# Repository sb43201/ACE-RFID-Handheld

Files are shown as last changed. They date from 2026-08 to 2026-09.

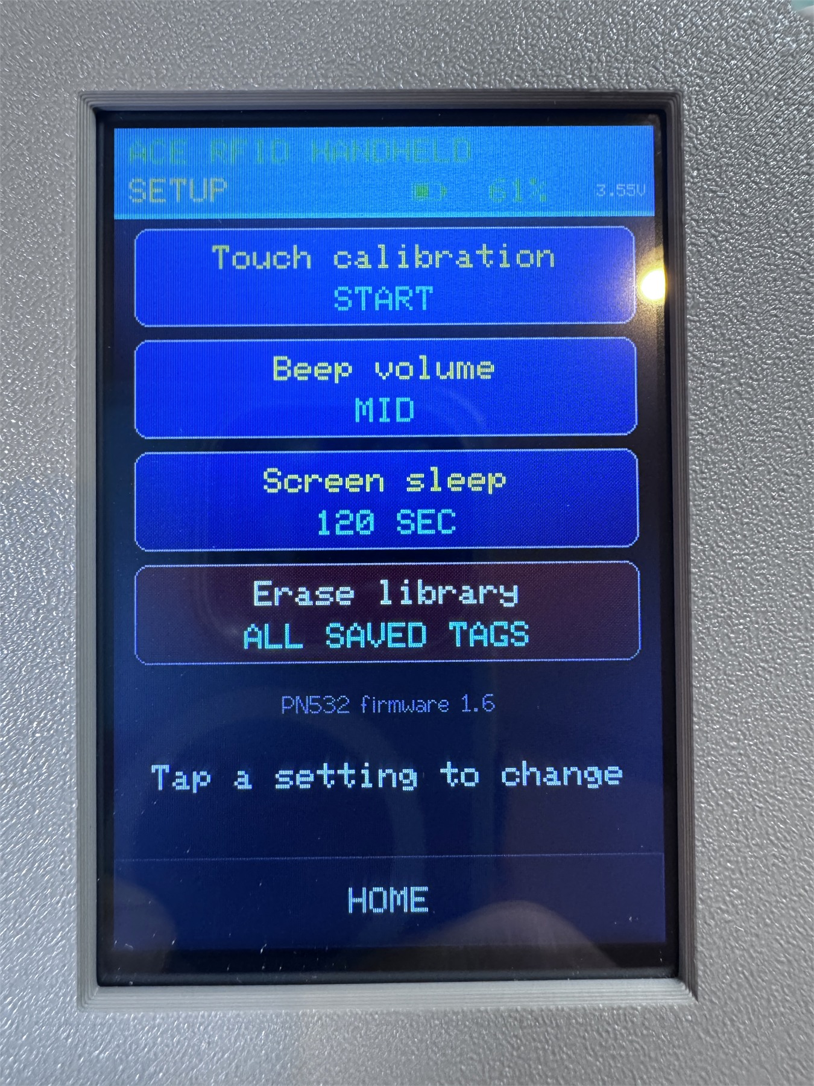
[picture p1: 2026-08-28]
images/09-setup-screen.jpg

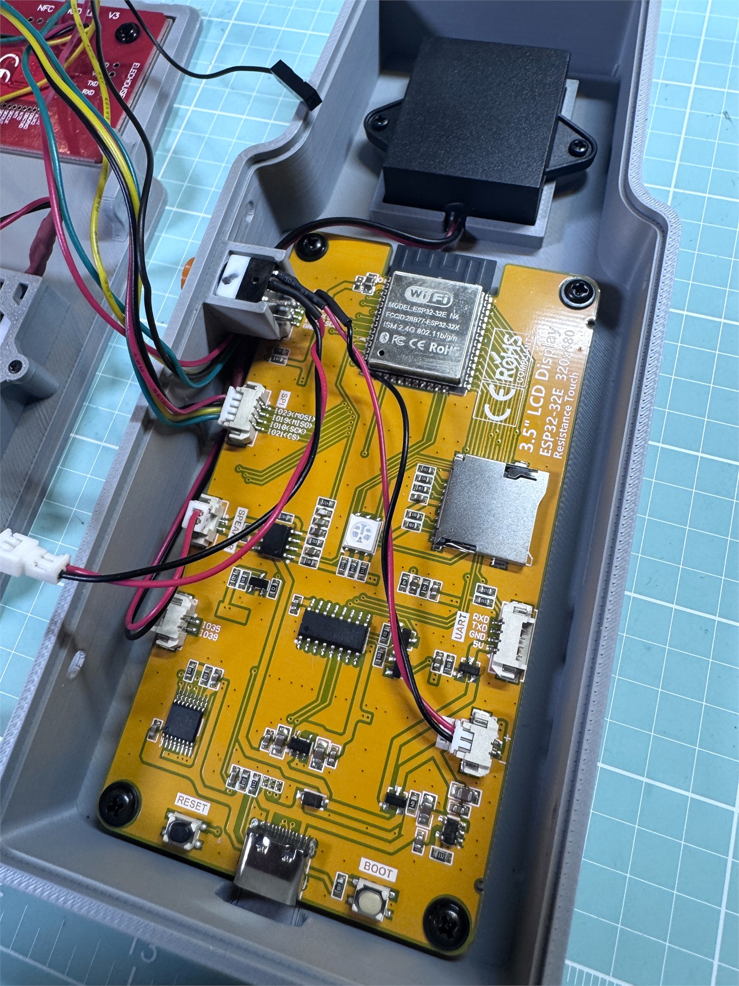
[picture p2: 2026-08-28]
images/02-controller-and-battery.jpg

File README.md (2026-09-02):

# ACE RFID Handheld

Portable ESP32 reader, writer, cloner, read-only emulator, and library for Anycubic ACE filament RFID tags.

The handheld combines a Hosyond/LCDWiki E32R35T 3.5-inch touchscreen with a PN532 NFC module. It reads ACE filament metadata, presents an accessible full-size color plate and color name, writes verified presets to compatible rewritable tags, clones ACE payloads, emulates tags to an ACE reader, and stores scanned or generated presets in onboard flash.

> This is an independent community project. It is not affiliated with or endorsed by Anycubic.

## Highlights

- Reads ACE data from NTAG-compatible tags and decodes material, color, SKU, nozzle range, bed range, diameter, and filament length.
- Large color plate and written color name for color-blind accessibility.
- Writes community, catalog, and factory-captured filament presets.
- Clones the complete ACE payload on pages 4–31 and verifies every byte.
- Emulates scanned, saved, and built-in preset tags in read-only PN532 target mode.
- Shows ACE read progress, blocks write commands during emulation, and provides an on-screen Cancel action.
- Detects factory-locked or incompatible tags and avoids reporting false success.
- Saves scanned tags and generated presets to a CRC-protected LittleFS library with duplicate handling, raw view, rewrite, emulation, and delete.
- Touchscreen setup for calibration, beep volume, and screen timeout.
- Battery icon, percentage, and voltage in the header.
- Wi-Fi and Bluetooth stacks are not linked or initialized, keeping both radios off for an offline, lower-power handheld.
- Musical startup, success, and error cues through the onboard speaker.
- Screen dim/off and touch wake based on the SwitchBot Blind Remote power-management pattern.

## Hardware

- Hosyond/LCDWiki E32R35T with ESP32, ST7796 320×480 TFT, and XPT2046 touch
- Elechouse-style PN532 NFC/RFID V3 module configured for SPI
- Common 3.3 V supply and ground

### Bill of materials

| Qty. | Component | Purchase link | Notes |
|---:|---|---|---|
| 1 | Hosyond 3.5-inch 320×480 Touch Screen ESP32 Display (Cheap Yellow Display) | [Amazon](https://a.co/d/01DXrowN) | Main ESP32, touchscreen, display, battery input, and microSD hardware |
| 1 | PN532 NXP NFC/RFID module | [Amazon](https://a.co/d/03boXSBR) | Configure the module for SPI mode |
| 1 | 3.7 V, 1000 mAh LiPo battery | [Amazon](https://a.co/d/0ji3c6oG) | Verify connector type and polarity before connecting |
| 1 | 4 Ω, 3 W mini speaker | [Amazon](https://a.co/d/07AWv2H9) | Audio feedback and startup/success/error cues |
| 1 | 8×8 mm DPDT tactile switch | [Amazon](https://a.co/d/04x0NMgU) | Power switch |
| 1 kit | 1.25 mm JST/Molex connector kit | [Amazon](https://a.co/d/0b7Jxc98) | Internal removable wiring connections |
| As required | NTAG213 RFID tags | [Amazon](https://a.co/d/0dDuntYi) | Rewritable test/destination tags; verify usable pages and lock state before writing |
| As required | Hookup wire, heat-shrink tubing, and small fasteners | — | Final lengths and fasteners depend on the enclosure build |
| 1 set | Printed handheld enclosure | [Enclosure files](enclosure/) | Print the matching front and rear enclosure parts |

Amazon links are provided for convenience and may change or become unavailable. Verify dimensions, voltage, pinout, and connector polarity before ordering or assembly. LiPo connector polarity is not standardized; reversed polarity can damage the handheld or battery.

### PN532 wiring

Disconnect power before changing the PN532 interface switches. Configure the module for **SPI mode**.

| PN532 | E32R35T | Purpose |
|---|---:|---|
| SCK | GPIO18 | VSPI clock |
| MISO | GPIO19 | VSPI controller input |
| MOSI | GPIO23 | VSPI controller output |
| SS | GPIO21 | PN532 chip select |
| VCC | 3.3 V | Power |
| GND | GND | Common ground |
| IRQ | Not connected | Polling is used |
| RSTPD_N | GPIO25 / SCL | Hard Power Down during ESP32 deep sleep |
| RSTO | Not connected | Not required by the current driver |

The PN532 antenna is mounted at the back of the handheld. Present tags to the rear antenna area.

### Complete pin map

| Subsystem | Signal | GPIO |
|---|---|---:|
| TFT | SCLK / MOSI / MISO | 14 / 13 / 12 |
| TFT | CS / DC / backlight | 15 / 2 / 27 |
| Touch | CS / IRQ | 33 / 36 |
| PN532 | SCK / MISO / MOSI / SS | 18 / 19 / 23 / 21 |
| PN532 | RSTPD_N | 25 (E32R35T SCL header) |
| Speaker | audio / active-low enable | 26 / 4 |
| Battery | ADC | 34 |

## Software

- PlatformIO
- Espressif Arduino framework for ESP32
- TFT_eSPI 2.5.43
- XPT2046_Touchscreen
- Adafruit PN532 1.3.4
- LittleFS and Preferences from the ESP32 framework

## Build and upload

1. Install [Visual Studio Code](https://code.visualstudio.com/) and the [PlatformIO extension](https://platformio.org/install/ide?install=vscode).
2. Clone this repository and open its folder in PlatformIO.
3. Connect the E32R35T by USB.
4. Build and upload:

```powershell
platformio run
platformio run --target upload
platformio device monitor
```

The serial monitor uses 115200 baud. Upload speed is configured as 921600 baud; reduce `upload_speed` in `platformio.ini` if a USB adapter is unreliable.

## Using the handheld

- Scan: hold an ACE tag near the antenna on the back.
- Write preset: choose `WRITE PRESET`, select a material and color, review the details, and explicitly arm writing.
- Clone: scan a valid ACE source, select `CLONE`, remove the source, and present a different rewritable destination.
- Emulate a scanned tag: scan it, select `EMU`, remove the source tag, and hold the handheld's PN532 antenna near the ACE sensor.
- Emulate a preset: choose `WRITE PRESET`, select a color, then use the yellow `EMU` button.
- Library: scan a valid ACE tag and select `SAVE`, or use the green `SAVE` button on a preset preview; open `LIBRARY` from the Ready screen to view saved records and emulate them later.
- Setup: long-press the Ready/Scan screen for about 1.2 seconds.

See the [User Manual](docs/USER_MANUAL.md) for complete operating and safety instructions.

## Important tag limitations

- Writing requires a compatible rewritable tag with at least pages 4–31 available.
- The writer currently accepts 7-byte UID destinations for ACE-compatible rewritable media.
- Genuine Anycubic factory tags are commonly locked. They can be read and saved, but attempts to alter them may correctly report `WRITE PROTECTED`.
- Writing and cloning affect only pages 4–31. Manufacturer/UID, lock, capability, and configuration pages are not intentionally changed.
- Never remove or exchange a tag during writing or verification.
- Test with expendable tags before relying on a newly purchased tag type.

## Emulation behavior

Emulation is intentionally read-only. The handheld responds to the ACE reader's page-read commands but refuses NFC write commands. The `READ ONLY - WRITES BLOCKED` message describes this behavior; it does not mean that the saved Library record is locked.

The ACE reader normally requests nine four-page blocks from page `04` through page `24`. The EMU progress display advances after each successful response. `READ COMPLETE` indicates that the complete expected read sequence was served. Use `CANCEL` to leave target mode and return to Library.

Before preset emulation, the firmware performs short passive-reader probes to place the PN532 in a reliable state. This replaces the previously observed need to visit Library between target-mode sessions.

Built-in presets do not originate from a physical NFC tag, so saving one to Library assigns it a deterministic synthetic seven-byte source UID. The same preset always receives the same UID, different preset payloads receive different UIDs, and printer recognition continues to come from the ACE payload fields.

## Data integrity

Writes are followed by a complete read-back of pages 4–31 and byte-for-byte verification. Clone data is captured by value before the destination is accepted. The saved-tag library uses versioned binary records, CRC32 validation, and a temporary-file/rename workflow.

The core read, preset-write, protection-detection, clone, Library, read-only emulation, sound, display, touch, battery, and power-management paths have been exercised on hardware. Saved genuine tags and consecutive built-in presets—including PLA, Silk, ABS, PC, and ASA examples—were recognized by an ACE reader during hardware testing. Users should still validate behavior on their own printer and keep copies of irreplaceable records.

## Technical references

- [ACE tag memory format](docs/ACE_TAG_FORMAT.md)
- [Factory tag captures](docs/FACTORY_TAG_CAPTURES.md)
- [Anycubic catalog preset provenance](docs/ANYCUBIC_CATALOG_PRESETS.md)

## Repository layout

```text
src/audio/     Musical cues and saved volume setting
src/config/    Hardware pin assignment
src/power/     Backlight, sleep, wake, and battery monitoring
src/rfid/      PN532 access, ACE codec, tag model, and presets
src/storage/   LittleFS saved-tag library
src/ui/        Touch handling and all 320×480 screens
docs/          User and technical documentation
images/        Project photographs, screenshots, and wiring images
enclosure/     Printable enclosure STL files and model exports
```

## Disclaimer

RFID writing can permanently alter compatible tags. Use this firmware at your own risk. Keep backups of known-good payloads and do not experiment on the only tag for a filament roll.

## License

This project is released under the [MIT License](LICENSE).

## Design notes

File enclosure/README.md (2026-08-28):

# Enclosure STL Files

Place printable STL enclosure files and related 3D-model exports for the ACE RFID Handheld here.

Include the model revision and part name in each filename, for example `ace-rfid-handheld-v1-front.stl` and `ace-rfid-handheld-v1-back.stl`.

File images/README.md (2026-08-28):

# Project Images

Place photographs, wiring images, screenshots, and other visual references for the ACE RFID Handheld here.

Use descriptive lowercase filenames, for example `finished-handheld-front.jpg` or `pn532-wiring.png`.

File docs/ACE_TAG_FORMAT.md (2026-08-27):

# ACE tag format used by ace-rfid-box

Pages are four bytes each. The handheld reads and preserves pages 4–31.

| Pages | Meaning |
|---|---|
| 4 | Header `7B 00 65 00` |
| 5–9 | SKU, 20-byte NUL-padded ASCII |
| 10–14 | Brand/source, 20-byte NUL-padded ASCII |
| 15–19 | Material, 20 bytes written; original reader uses first 16 |
| 20 | RRGGBBAA stored in reverse byte order |
| 21–23 | Reserved/zero in generated tags |
| 24 | Nozzle minimum and maximum, two little-endian uint16 values |
| 25–28 | Reserved/zero in generated tags |
| 29 | Bed minimum and maximum, two little-endian uint16 values |
| 30 | Diameter ×100 and length in meters, little-endian uint16 values |
| 31 | Fixed footer `E8 03 00 00` (1000 little-endian) |

Stage 3 validation requires the exact header and footer, printable non-empty SKU/brand/material fields, and structurally plausible numeric values. Color names are looked up from the original preset table because only the RGBA value is stored on the tag.

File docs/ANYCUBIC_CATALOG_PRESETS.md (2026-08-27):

# Anycubic catalog-derived presets

Stage 5.1 includes 123 `CATALOG` presets derived from the current Anycubic filament catalog and public ACE material-family mappings.

## Included families

| Family | Colors | Encoded material | Family SKU used | Nozzle | Bed |
|---|---:|---|---|---|---|
| PLA Basic | 29 | PLA | AHPLBK-101 | 190-230 C | 55-65 C |
| PLA+ | 20 | PLA+ | AHPLPBK-102 | 190-230 C | 55-65 C |
| PLA High Speed | 10 | PLA | AHHSBK-103 | 190-260 C | 55-65 C |
| PLA Matte | 22 | PLA | HYGBK-102 | 190-230 C | 60-65 C |
| PLA Silk | 11 | Silk | AHSCWH-102 | 210-240 C | 55-65 C |
| PLA Marble | 2 | PLA | AHPLM-001 | 200-230 C | 55-65 C |
| PETG Translucent | 8 | PETG | AHPETG-001 | 230-250 C | 60-70 C |
| TPU 95A | 6 | TPU | STPBK-101 | 195-230 C | 50-60 C |
| ABS | 9 | ABS | SHABBK-102 | 240-280 C | 80-100 C |
| ASA | 4 | ASA | AHASA-001 | 255-275 C | 80-100 C |
| PC | 2 | PC | AHPC-001 | 270-290 C | 100-120 C |

The database contains 186 total presets: 58 original community presets, 5 factory-verified captures, and 123 catalog-derived presets.

## Confidence and limitations

`CATALOG` means the color hex and temperature ranges come from current official Anycubic product listings, while material bytes and family SKU patterns come from the public Anycubic ACE RFID editor mapping. These are not factory RFID page captures.

- Anycubic does not publish the exact per-color RFID SKU for most catalog colors. A documented family SKU is therefore reused within each family.
- Diameter is 1.75 mm. Length remains the legacy ACE writer default of 330 m because catalog pages publish mass rather than encoded RFID length.
- Page 23 remains zero for catalog presets because its bytes are not published for these families.
- The printer may recognize material and color without treating a catalog-derived tag exactly like an official factory tag.

## Deliberately excluded

- Rainbow, dual-color, and tri-color products: one ACE color field cannot represent multiple colors accurately.
- Glow variants lacking an official single color hex.
- ABS, TPU, and PC variants whose catalog listing omits a hex value.
- PLA Galaxy and PLA Metal: official colors/settings exist, but no authoritative RFID family SKU mapping was found.
- Carbon-fiber, PA6-CF, PET-CF, PVA, and other families without a sufficiently documented ACE RFID material/SKU mapping.

These entries should be added only after an actual factory tag capture or another byte-level authoritative source becomes available.

## Sources

- https://store.anycubic.com/collections/filaments
- https://store.anycubic.com/products/pla-basic-mix-match-deal
- https://github.com/OrochW/Anycubic-ACE-RFID-Tool

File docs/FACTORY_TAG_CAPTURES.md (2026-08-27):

# Factory-verified ACE presets

These records were captured directly by the handheld from protected Anycubic factory filament tags. They are kept distinct from the original community preset database.

| Preset | SKU | Material | Color | Nozzle | Bed | Diameter | Length | Page 23 |
|---|---|---|---|---|---|---|---|---|
| PLA+ Orange Official | AHPLPVO-108 | PLA+ | FF7F32FF | 190-230 C | 55-65 C | 1.75 mm | 330 m | 32 00 C8 00 |
| PLA Texture Grey Official | AHPLGY-106 | PLA | 75787BFF | 190-230 C | 55-65 C | 1.75 mm | 330 m | 32 00 C8 00 |
| PLA Black Official | AHPLBK-107 | PLA | 212721FF | 190-230 C | 55-65 C | 1.75 mm | 330 m | 32 00 C8 00 |
| PETG White Official | AHPEBW-102 | PETG | EFF0F1FF | 230-250 C | 60-70 C | 1.75 mm | 320 m | 32 00 C8 00 |
| PETG Black Official | AHPEBK-102 | PETG | 212721FF | 230-250 C | 60-70 C | 1.75 mm | 320 m | 32 00 C8 00 |

`Page 23` is reproduced byte-for-byte for these verified variants. Its semantic meaning remains undocumented, so it is described as an auxiliary pair rather than assigned an inferred label.

Factory tags are protected and are references only. Stage 5.1 writes these images to separate compatible rewritable tags.

## Validation status

- PLA+ Orange Official: write, byte-for-byte verification, removal/re-arm, and normal rescan passed on a rewritable tag in approximately 2.125 seconds.
- PLA Black Official: pending write/rescan validation.
- PLA Texture Grey Official: pending write/rescan validation.
- PETG Black Official: pending write/rescan validation.
- PETG White Official: pending write/rescan validation.

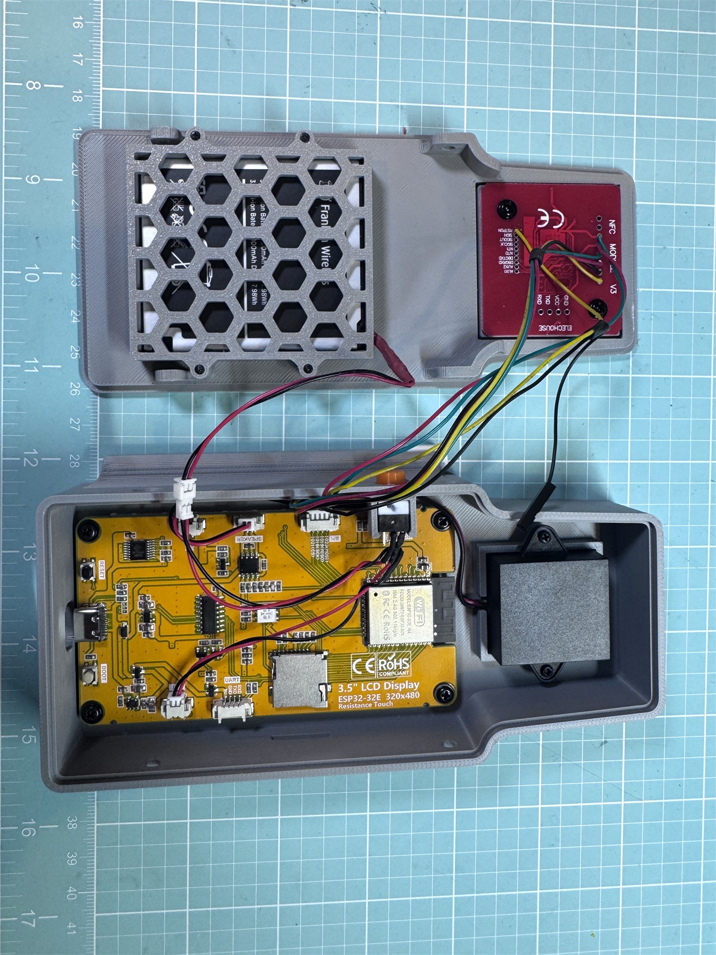
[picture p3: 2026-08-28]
images/01-internal-layout.jpg

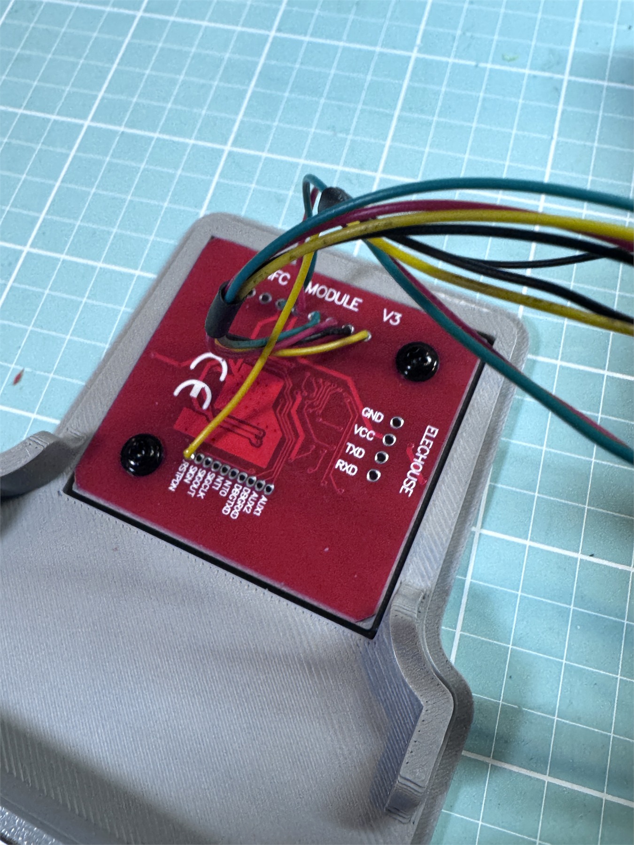
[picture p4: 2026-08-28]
images/03-pn532-module.jpg

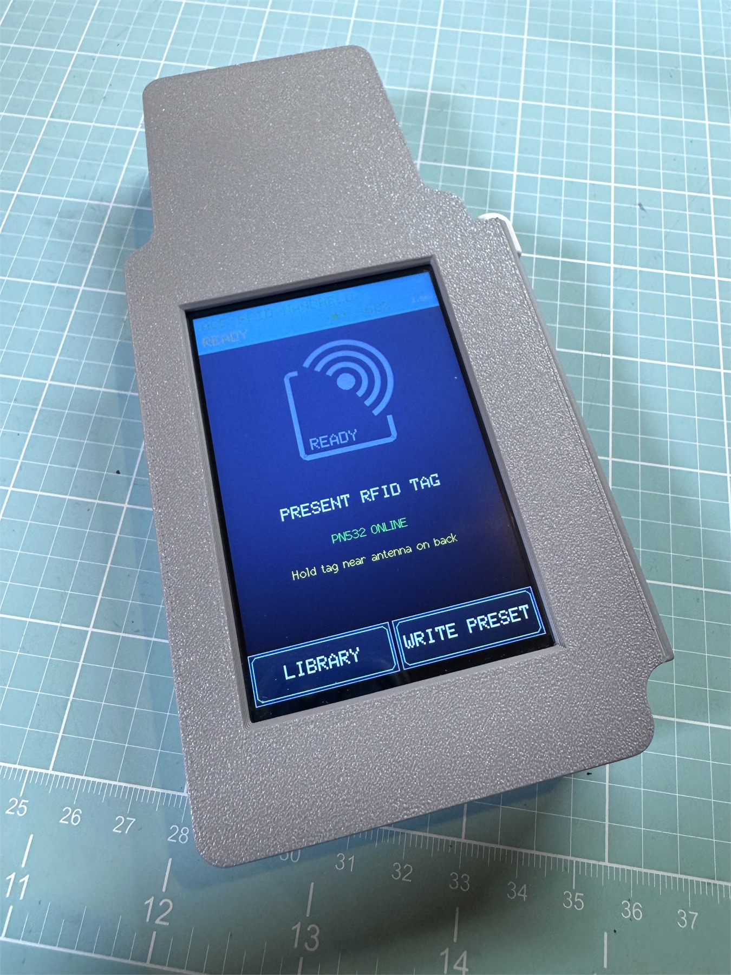
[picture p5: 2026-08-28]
images/04-handheld-front.jpg

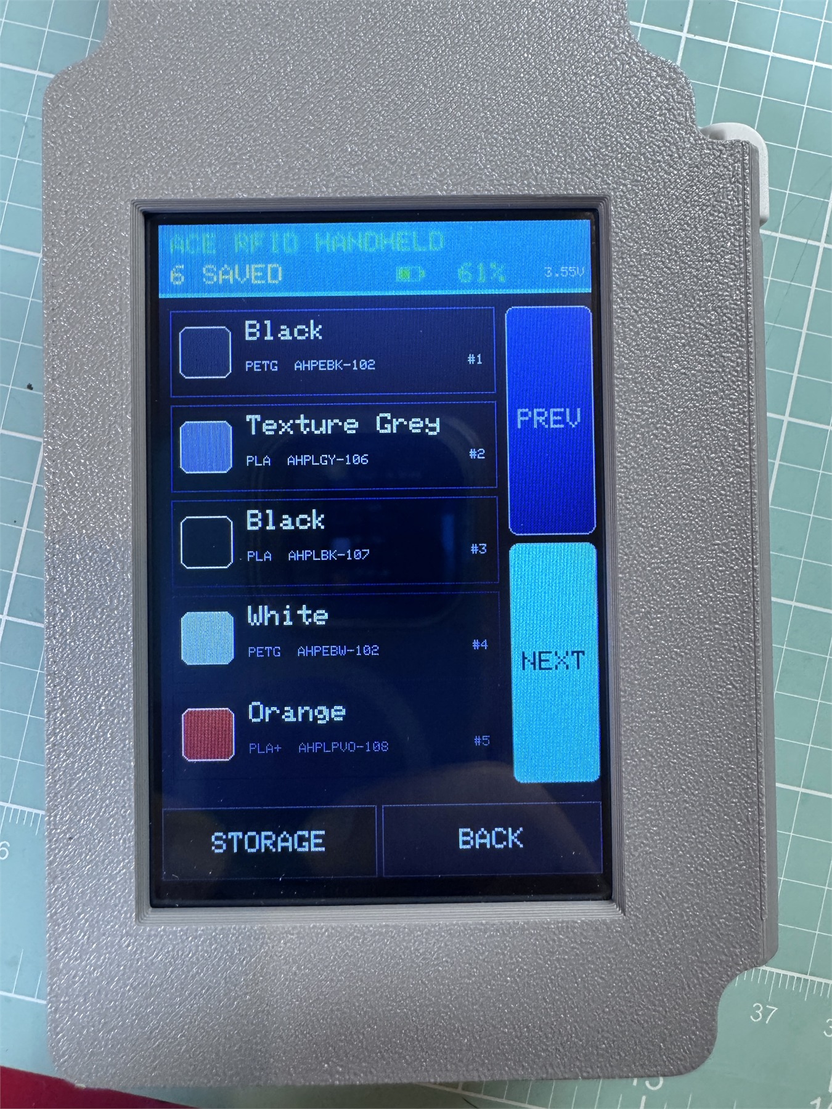
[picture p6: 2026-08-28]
images/07-library-screen.jpg

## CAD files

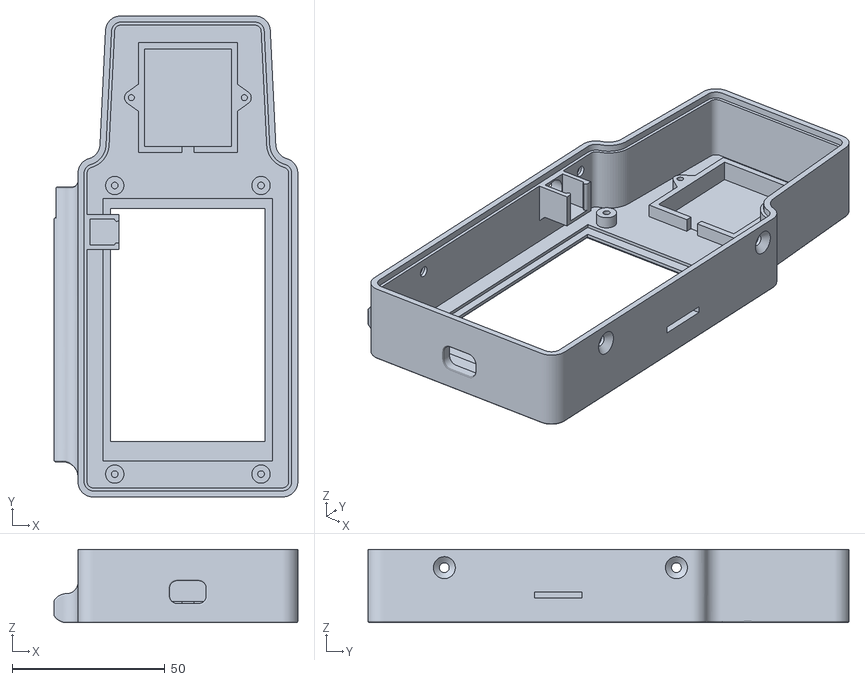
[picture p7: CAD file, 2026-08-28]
enclosure/ACE RFID Pro - Case front.stl
79.8 x 157.5 x 24.0

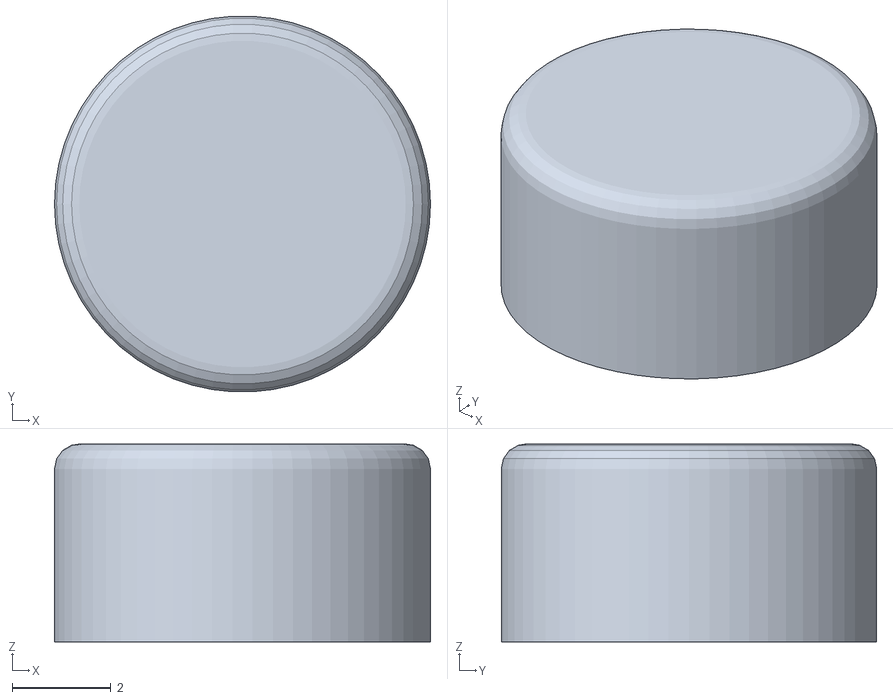
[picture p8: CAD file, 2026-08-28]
enclosure/ACE RFID Pro - PS Button.stl
7.60 x 7.59 x 4.00

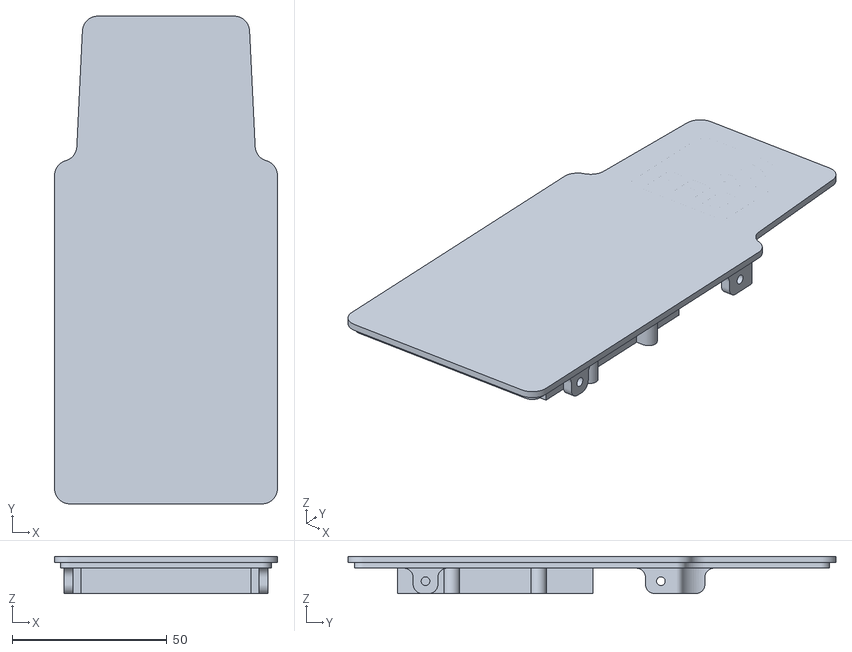
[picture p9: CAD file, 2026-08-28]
enclosure/ACE RFID Pro - Case back.stl
72.0 x 157.5 x 12.0

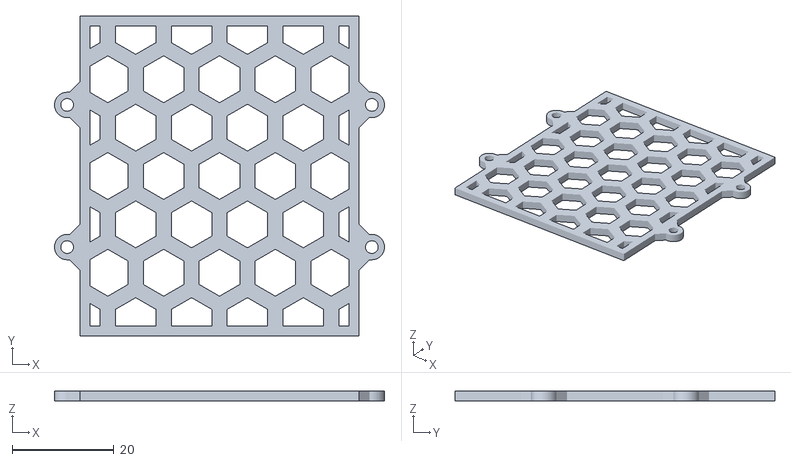
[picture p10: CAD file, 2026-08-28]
enclosure/ACE RFID Pro - Battery hold down.stl
65.0 x 63.0 x 2.00

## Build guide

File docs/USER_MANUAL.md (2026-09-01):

# ACE RFID Handheld User Manual

## 1. Overview

ACE RFID Handheld reads and manages RFID tags used with Anycubic ACE filament systems. Its main functions are:

- Scan and identify an ACE filament tag
- Display the filament type and a large written color name
- Inspect raw tag pages
- Write a selected filament preset to a compatible blank or rewritable tag
- Clone an existing ACE tag to another compatible tag
- Save scanned ACE tags in the handheld library
- Emulate scanned tags, saved Library records, and built-in presets to an ACE reader
- Save built-in presets directly to the Library

The RFID antenna is on the **back** of the handheld.

## 2. Starting the handheld

1. Power on or reset the device.
2. Wait for the Ready screen.
3. Confirm that the screen reports `PN532 ONLINE`.
4. Hold the tag flat near the antenna area on the back.

A musical cue confirms startup and a successful tag detection. The header shows battery percentage and voltage.

## 3. Ready screen

The Ready screen provides two actions:

- `LIBRARY` opens saved tags.
- `WRITE PRESET` opens the filament preset catalog.

The RFID graphic is also the scan target/status area. Long-press the Ready screen for approximately 1.2 seconds to open Setup.

## 4. Scanning a tag

1. Place one tag near the rear antenna.
2. Hold it still while the handheld reads pages 4–31.
3. The result screen shows a large color plate and written color name, followed by material, SKU, temperature ranges, diameter, length, and UID.
4. Remove the tag when reading is complete. The result remains available until another tag is scanned or Home is selected.

Possible results:

- `ACE TAG`: a complete, valid ACE payload was decoded.
- `NFC TAG`: the tag is readable but is not recognized as ACE data.
- `UNSUPPORTED`: the tag type or memory layout is unsuitable.
- `READ ERROR`: the required memory could not be read; remove and retry.

## 5. Result-screen actions

- `RAW` displays the retained bytes for pages 4–31.
- `CLONE` captures the displayed ACE payload as a clone source.
- `SAVE` stores the tag in the onboard library.
- `EMU` starts read-only tag emulation using the displayed ACE payload.
- `WRITE` opens the preset writer.
- `HOME` returns to the Ready screen.

## 6. Writing a filament preset

### Select a preset

1. Select `WRITE PRESET`.
2. Choose a material tab such as PLA, PLA+, PETG, TPU, or Other.
3. Use `PREV` and `NEXT` to change pages.
4. Tap a numbered color row.
5. Review the large color plate, color name, material, SKU, and encoded values.
6. Choose one of the four preview actions:
   - `BACK` returns to preset selection.
   - Yellow `EMU` starts read-only emulation of the preset.
   - Green `SAVE` stores the preset in Library.
   - Cyan `WRITE` arms physical tag writing.

### Write the tag

1. Remove all tags until the handheld reports that destination detection is armed.
2. Place one compatible rewritable tag near the rear antenna.
3. Keep that same tag completely still through writing and verification.
4. Wait for `WRITE COMPLETE`, with both Write and Verify marked `PASS`.

Do not remove, slide, stack, or exchange tags during this operation.

### Write failures

- `WRITE PROTECTED`: the tag accepted no effective change or is factory locked.
- `SAME TAG`: a clone destination is the captured source tag.
- `WRITE FAILED`: the tag moved, communication failed, or the memory is incompatible.
- `VERIFY FAILED`: written bytes did not match the intended payload.
- `PARTIAL ACE DATA`: some pages may have changed before the failure. Rewrite the complete intended image before using that tag.

Many genuine Anycubic factory filament tags are protected. Reading them is safe; rewriting may not be possible.

## 7. Emulating an ACE tag

Emulation makes the PN532 behave like an NFC target so an external ACE reader can read the selected filament data. It does not write or modify the printer.

### From a scanned tag

1. Scan a valid ACE tag.
2. Remove the source tag.
3. Select `EMU` on the result screen.
4. Hold the handheld's rear PN532 antenna near the printer or ACE NFC sensor.
5. Keep it steady while the nine progress segments fill.
6. Wait for `READ COMPLETE`, then remove the handheld from the sensor.

### From a preset

1. Open `WRITE PRESET` and select a material and color.
2. Review the preset details.
3. Select the yellow `EMU` button.
4. Hold the rear antenna near the ACE sensor until the read completes.

### From Library

1. Open `LIBRARY` and select a saved record.
2. Select `EMU`.
3. Hold the rear antenna near the ACE sensor until the read completes.

The EMU screen shows `READ ONLY - WRITES BLOCKED`. The handheld serves page-read requests but deliberately refuses NFC write commands. The progress bar represents the expected ACE reads from pages `04` through `24`.

Select `CANCEL` to stop waiting and return to Library. Touch input is limited to Cancel during the active RF session. Before preset emulation, the handheld automatically primes the PN532 reader state; no Library detour or manual reset is required between consecutive presets.

Possible results:

- `READ COMPLETE`: the expected ACE page sequence was served.
- `NO ACE READER DETECTED`: no external initiator activated the target before timeout.
- `PN532 TARGET TRANSPORT ERROR`: the PN532 did not acknowledge or complete a target-mode command.
- `ACE SCAN WAS INTERRUPTED`: activation ended before the expected page sequence completed.

## 8. Cloning a tag

1. Scan a valid ACE source tag.
2. Remove it after the result is displayed.
3. Select `CLONE`.
4. Keep the antenna area clear until destination detection is armed.
5. Present a different compatible rewritable destination tag.
6. Hold it still until clone writing and full verification pass.

Cloning copies the exact 112-byte ACE payload from pages 4–31. It does not copy the source UID or manufacturer pages.

## 9. Saved-tag library

### Save

1. Scan a valid ACE tag.
2. Select `SAVE`.
3. If the same source UID already exists, choose whether to save another copy or cancel.

To save a built-in preset, open its preview and select the green `SAVE` button. Because a preset has no physical factory UID, the handheld creates a stable synthetic source UID from the preset payload. Saving the same preset again produces the same UID and is detected as a duplicate; different preset payloads receive different UIDs. The synthetic UID does not change the material information recognized by the printer.

### Browse

1. From Ready, select `LIBRARY`.
2. Use `PREV` and `NEXT` on the right edge.
3. Tap a row to open its details.

Saved details allow you to view raw data, emulate the record, write a copy to a compatible destination, or delete the record. `STORAGE` shows filesystem capacity and record counts.

If storage has never been initialized and is unavailable, use the red Format action only after confirming that no saved data must be preserved. Formatting erases the handheld library but does not affect RFID tags.

## 10. Setup

Long-press the Ready/Scan screen for approximately 1.2 seconds.

### Touch calibration

Select `Touch calibration`, then touch and release each displayed target accurately. Calibration is stored in nonvolatile memory.

### Beep volume

Tap `Beep volume` to cycle through High, Mid, Low, and Mute. The selected setting is stored.

### Screen sleep

Tap `Screen sleep` to cycle through:

- 30 seconds
- 60 seconds
- 120 seconds
- Always On

For a timed mode, the display dims halfway to the selected off time and turns the backlight fully off at the selected time. RFID scanning continues while the display is off. Tag or touch activity wakes the display. After prolonged inactivity, the handheld can enter deep sleep and wake from the touchscreen interrupt. Always On disables automatic dim, off, and deep sleep.

During deep sleep, GPIO25 holds the PN532 `RSTPD_N` input low to place the reader in Hard Power Down. Touching the screen wakes the ESP32 and re-enables the PN532.

Select `HOME` to return to Ready.

### Erase library

Select the red `Erase library` setting to remove every saved tag from internal
storage. A separate confirmation screen explains that RFID tags are not
affected and requires an explicit `ERASE` tap. This action cannot be undone.
Use `CANCEL` to return to Setup without changing the library.

## 11. Battery display

The header shows:

- Battery icon
- Estimated charge percentage
- Measured battery voltage

Percentage is an estimate derived from voltage and is most useful as a trend. Load, charging state, and battery condition can cause short-term variation.

## 12. Care and troubleshooting

### PN532 not found

- Turn power off.
- Confirm the PN532 is set to SPI mode.
- Check GPIO18, GPIO19, GPIO23, GPIO21, 3.3 V, and ground.
- Confirm that IRQ and RSTO are left unconnected for this firmware.

### Tag is not detected

- Place it against the back antenna area, not the screen.
- Remove other nearby tags.
- Hold it flat and still.
- Try rotating or shifting it slightly across the rear antenna.

### Touch is inaccurate

Open Setup with a long press and repeat Touch calibration.

### Screen does not sleep

Check Setup for `ALWAYS ON`. Writing, cloning, verification, held touch, and active melodies temporarily prevent sleep.

### A factory tag will not write

This is expected for many protected tags. Use a known compatible rewritable tag. Do not repeatedly attempt writes to a valued factory tag.

### Emulation immediately reports a PN532 transport error

- Confirm that the firmware includes automatic PN532 preset priming.
- Retry once after leaving the printer's NFC field.
- Check the serial monitor for `command 8C ACK failed` or `command 8C response failed`.
- Verify that TFT, touch, SD, and PN532 chip-select wiring matches the documented pin map; these devices share SPI resources.

### Printer does not recognize an emulated preset

- Hold the rear antenna flat and centered over the ACE sensor.
- Keep the handheld in place until all nine progress segments fill.
- Confirm that the selected preset's SKU, material, and color are correct.
- Catalog-derived presets may not have the same validation history as factory-captured tag data.

## 13. Safety and data protection

- Use 3.3 V logic and a common ground.
- Disconnect power before rewiring or changing PN532 switches.
- Test tag writing with expendable media.
- Never assume that a successful command means a successful write; wait for the handheld’s full verification result.
- Save or record known-good tag data before experimentation.
- Do not use a partially written tag in an ACE system until it has been completely rewritten and verified.

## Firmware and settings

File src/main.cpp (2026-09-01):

#include <Arduino.h>
#include <SPI.h>

#include "config/Hardware.h"
#include "audio/MelodyPlayer.h"
#include "rfid/Pn532Reader.h"
#include "rfid/Pn532TargetEmulator.h"
#include "rfid/AceCodec.h"
#include "rfid/AcePresets.h"
#include "power/PowerManager.h"
#include "power/BatteryMonitor.h"
#include "ui/Ui.h"
#include "storage/TagLibrary.h"

Ui ui;
SPIClass pn532Spi(VSPI);
Pn532Reader reader(Hardware::PN532_SS, pn532Spi);
Pn532TargetEmulator targetEmulator(Hardware::PN532_SS, pn532Spi);
MelodyPlayer melody;
PowerManager power;
BatteryMonitor battery;
TagLibrary library;

enum class WriteState : uint8_t {
  Idle, WaitingForClear, WaitingForDestination, Writing, Verifying, Success, Failed
};
enum class OperationMode : uint8_t { None, PresetWrite, Clone, SavedCopy };
WriteState writeState = WriteState::Idle;
OperationMode operationMode = OperationMode::None;
AceTagData intendedTag;
AceTagData destinationTag;
AceTagData cloneSource;
uint8_t writePage = 4;
uint32_t clearSinceMs = 0;
bool wroteAnyPage = false;
uint32_t writeStartedMs = 0;
uint8_t verificationReadAttempt = 0;

void updateEmulationProgress(uint8_t startPage) {
  ui.showEmulationProgress(startPage);
}

bool checkEmulationCancel() {
  return ui.emulationCancelRequested();
}

void assignPresetUid(AceTagData &tag) {
  // Saved records require a UID. Built-in presets have no physical source
  // tag, so derive a stable seven-byte identifier from their ACE payload.
  uint64_t hash = 1469598103934665603ULL;
  for (uint8_t page = 4; page <= 31; ++page) {
    for (uint8_t column = 0; column < 4; ++column) {
      hash ^= tag.pages[page][column];
      hash *= 1099511628211ULL;
    }
  }
  tag.uidLength = 7;
  tag.uid[0] = 0x04;
  for (uint8_t i = 1; i < 7; ++i) tag.uid[i] = hash >> ((i - 1) * 8);
  String uid;
  for (uint8_t i = 0; i < tag.uidLength; ++i) {
    if (i) uid += ':';
    if (tag.uid[i] < 0x10) uid += '0';
    uid += String(tag.uid[i], HEX);
  }
  uid.toUpperCase();
  tag.uidText = uid;
}

void emulateTag(const AceTagData &tag, bool fromSaved, bool fromPreset = false) {
  if (!tag.readOk || !tag.aceValid) {
    ui.showEmulationResult(false, "Valid ACE tag data required");
    melody.play(MelodyPlayer::Cue::Error);
    return;
  }
  Serial.printf("[emu] Source=%s UID=%s SKU=%s\n",
                fromSaved ? "LIBRARY" : fromPreset ? "PRESET" : "PRESENT",
                tag.uidText.c_str(), tag.sku);
  ui.showEmulationWaiting(tag, fromSaved, fromPreset);
  power.wakeDisplayForRfid();

  if (fromPreset) {
    // Library/Saved screens leave normal reader polling active, but the
    // Write/Preset workflow intentionally suppresses reader.poll(). After a
    // completed target session the PN532 needs an initiator command cycle
    // before it will reliably ACK TgInitAsTarget again. Mirror the Library
    // path here without allowing the discarded probe to change the UI.
    Serial.println("[emu] Priming PN532 reader state before preset target mode");
    AceTagData ignoredProbe;
    for (uint8_t attempt = 0; attempt < 3; ++attempt) {
      reader.detectTag(ignoredProbe, 80);
      delay(10);
    }
  }

  const EmulationResult result = targetEmulator.run(
      tag, 60000, updateEmulationProgress, checkEmulationCancel);

  // Target mode changes the PN532 state. A hardware reset guarantees that
  // normal handheld reader mode is restored even after activation timeout.
  digitalWrite(Hardware::PN532_RSTPD_N, LOW);
  delay(2);
  digitalWrite(Hardware::PN532_RSTPD_N, HIGH);
  delay(10);
  const Pn532Status restored = reader.begin();
  Serial.printf("[emu] Reader restore %s\n",
                restored.found && restored.samConfigured ? "PASS" : "FAILED");

  if (result == EmulationResult::Cancelled) {
    Serial.println("[emu] Cancelled by user; returning to library");
    ui.showLibrary(library.entries(), library.available(), library.totalBytes(),
                   library.usedBytes(), library.invalidCount());
    return;
  }

  const bool complete = result == EmulationResult::Complete;
  const char *detail = complete ? "ACE read pages 4-39" :
                       result == EmulationResult::Interrupted ? "ACE scan was interrupted" :
                       result == EmulationResult::Timeout ? "No ACE reader detected" :
                       "PN532 target transport error";
  ui.showEmulationResult(complete, detail);
  melody.play(complete ? MelodyPlayer::Cue::TagFound : MelodyPlayer::Cue::Error);
}

bool isCopyMode() {
  return operationMode == OperationMode::Clone || operationMode == OperationMode::SavedCopy;
}

const char *operationLogName() {
  return operationMode == OperationMode::Clone ? "clone" :
         operationMode == OperationMode::SavedCopy ? "library" : "write";
}

void beginWriteAttempt() {
  operationMode = OperationMode::PresetWrite;
  ui.setCloneMode(false);
  AcePresets::buildTag(ui.selectedPreset(), intendedTag);
  Serial.printf("[write] Selected preset: %s\n", ui.selectedPreset().name);
  Serial.println("[write] Intended ACE image:");
  for (uint8_t page = 4; page <= 31; ++page)
    Serial.printf("[write] P%02u: %02X %02X %02X %02X\n", page,
                  intendedTag.pages[page][0], intendedTag.pages[page][1],
                  intendedTag.pages[page][2], intendedTag.pages[page][3]);
  writeState = WriteState::WaitingForClear;
  clearSinceMs = 0;
  wroteAnyPage = false;
}

void beginClone(bool captureSource) {
  operationMode = OperationMode::Clone;
  ui.setCloneMode(true);
  if (captureSource) {
    cloneSource = ui.retainedTag();  // Dedicated by-value snapshot; never replaced by destination scans.
    if (!cloneSource.readOk || !cloneSource.aceValid) {
      Serial.println("[clone] FAIL SOURCE NOT ACE: retained source is incomplete or invalid");
      ui.showWriteFailure("SOURCE NOT ACE", "Valid ACE source required", false);
      melody.play(MelodyPlayer::Cue::Error);
      writeState = WriteState::Failed;
      return;
    }
    Serial.printf("[clone] Source captured UID=%s material=%s color=%s SKU=%s\n",
                  cloneSource.uidText.c_str(), cloneSource.material,
                  cloneSource.colorName, cloneSource.sku);
    Serial.println("[clone] Source payload pages 4-31:");
    for (uint8_t page = 4; page <= 31; ++page)
      Serial.printf("[clone] P%02u: %02X %02X %02X %02X\n", page,
                    cloneSource.pages[page][0], cloneSource.pages[page][1],
                    cloneSource.pages[page][2], cloneSource.pages[page][3]);
  }
  intendedTag = cloneSource;  // Exact raw ACE user payload, including reserved bytes.
  writeState = WriteState::WaitingForClear;
  clearSinceMs = 0;
  wroteAnyPage = false;
  ui.showCloneCaptured(cloneSource);
  melody.play(MelodyPlayer::Cue::TagFound);
}

void beginSavedCopy(bool captureSource) {
  operationMode = OperationMode::SavedCopy;
  ui.setCloneMode(true);
  if (captureSource) cloneSource = ui.selectedSavedTag();
  intendedTag = cloneSource;
  writeState = WriteState::WaitingForClear;
  clearSinceMs = 0;
  wroteAnyPage = false;
  ui.showSavedCopyCaptured(cloneSource);
  Serial.printf("[library] Write-copy armed from ID=%lu; pages 4-31 retained\n",
                static_cast<unsigned long>(ui.selectedLibraryId()));
}

void failWrite(const char *title, const String &detail) {
  Serial.printf("[%s] FAIL %s: %s partial=%s\n",
                operationLogName(),
                title, detail.c_str(), wroteAnyPage ? "YES" : "NO");
  ui.showWriteFailure(title, detail.c_str(), wroteAnyPage);
  melody.play(MelodyPlayer::Cue::Error);
  writeState = WriteState::Failed;
}

void setup() {
  Serial.begin(115200);
  Serial.println();
  Serial.println("[boot] ACE RFID Handheld");

  // This handheld is fully offline. No Wi-Fi, Bluetooth Classic, or BLE
  // library is linked or initialized, so both ESP32 radios remain off.
  Serial.println("[power] WiFi=OFF Bluetooth=OFF (not initialized)");

  ui.begin();
  battery.begin();
  ui.updateBattery(battery.percent(), battery.millivolts());
  // TFT_eSPI configures GPIO27 during tft.init(). Attach backlight PWM only
  // afterwards so TFT initialization cannot replace the LEDC output.
  power.begin();
  melody.begin();
  ui.calibrateIfNeeded();
  ui.showBoot();

  library.begin();  // Failure only disables SAVE/LIBRARY; RFID remains operational.

  pinMode(5, OUTPUT);
  digitalWrite(5, HIGH);  // Keep onboard microSD deselected on shared VSPI.
  pn532Spi.begin(Hardware::PN532_SCK, Hardware::PN532_MISO,
                 Hardware::PN532_MOSI, Hardware::PN532_SS);
  Serial.printf("[spi] PN532 VSPI started SCK=%u MISO=%u MOSI=%u SS=%u\n",
                Hardware::PN532_SCK, Hardware::PN532_MISO,
                Hardware::PN532_MOSI, Hardware::PN532_SS);

  const Pn532Status status = reader.begin();
  if (!status.found) {
    Serial.println("[rfid] PN532 not detected");
    melody.play(MelodyPlayer::Cue::Error);
  } else {
    Serial.printf("[rfid] PN532 found chip=0x%02X firmware=%u.%u support=0x%02X\n",
                  status.chip, status.firmwareMajor, status.firmwareMinor,
                  status.support);
    Serial.printf("[rfid] SAM configuration %s\n",
                  status.samConfigured ? "successful" : "FAILED");
    melody.play(status.samConfigured ? MelodyPlayer::Cue::Startup
                                     : MelodyPlayer::Cue::Error);
  }
  ui.showReaderStatus(status);
}

void loop() {
  melody.update();
  if (battery.update()) ui.updateBattery(battery.percent(), battery.millivolts());
  const UiTouchSample touch = ui.sampleTouch();
  power.handleTouch(touch.down);
  const UiAction action = ui.handleTouch(touch, power.controlsAllowed());
  if (action == UiAction::OpenSetup)
    ui.showSetup(melody.volumeLabel(), power.screenTimeoutSeconds());
  if (action == UiAction::CalibrateTouch) {
    ui.runTouchCalibration();
    ui.showSetup(melody.volumeLabel(), power.screenTimeoutSeconds());
  }
  if (action == UiAction::CycleVolume) {
    const uint8_t next = (static_cast<uint8_t>(melody.volume()) + 1) % 4;
    melody.setVolume(static_cast<MelodyPlayer::Volume>(next));
    if (melody.volume() != MelodyPlayer::Volume::Mute)
      melody.play(MelodyPlayer::Cue::TagFound);
    ui.showSetup(melody.volumeLabel(), power.screenTimeoutSeconds());
  }
  if (action == UiAction::CycleScreenTimeout) {
    const uint16_t current = power.screenTimeoutSeconds();
    const uint16_t next = current == 0 ? 30 : current == 30 ? 60 : current == 60 ? 120 : 0;
    power.setScreenTimeoutSeconds(next);
    ui.showSetup(melody.volumeLabel(), power.screenTimeoutSeconds());
  }
  if (action == UiAction::CloseSetup) ui.showReaderStatus(reader.status());
  if (action == UiAction::OpenLibrary || action == UiAction::RefreshLibrary) {
    if (library.available()) library.refresh();
    ui.showLibrary(library.entries(), library.available(), library.totalBytes(),
                   library.usedBytes(), library.invalidCount());
  }
  if (action == UiAction::FormatStorage) {
    const bool ok = library.formatAndBegin();
    if (ok) library.refresh();
    ui.showLibrary(library.entries(), library.available(), library.totalBytes(),
                   library.usedBytes(), library.invalidCount());
    melody.play(ok ? MelodyPlayer::Cue::TagFound : MelodyPlayer::Cue::Error);
  }
  if (action == UiAction::SaveTag || action == UiAction::SaveCopy) {
    const bool allowDuplicate = action == UiAction::SaveCopy;
    uint32_t savedId = 0;
    const LibrarySaveResult result = library.save(ui.retainedTag(), allowDuplicate, savedId);
    if (result == LibrarySaveResult::Duplicate) {
      ui.showSaveDuplicate();
    } else {
      const bool ok = result == LibrarySaveResult::Ok;
      const char *message = ok ? "Saved to internal flash" :
                            result == LibrarySaveResult::Unavailable ? "Internal storage unavailable" :
                            result == LibrarySaveResult::Full ? "Storage full - delete saved tags" :
                            result == LibrarySaveResult::InvalidSource ? "Valid ACE source required" :
                            result == LibrarySaveResult::CommitFailed ? "Could not commit saved file" :
                            "Could not write saved file";
      ui.showSaveResult(ok, savedId, message);
      melody.play(ok ? MelodyPlayer::Cue::TagFound : MelodyPlayer::Cue::Error);
    }
  }
  if (action == UiAction::OpenSaved) {
    AceTagData saved;
    if (library.load(ui.selectedLibraryId(), saved)) ui.showSavedDetail(ui.selectedLibraryId(), saved);
    else ui.showSaveResult(false, 0, "Saved record is invalid or missing");
  }
  if (action == UiAction::ConfirmDelete) {
    if (library.remove(ui.selectedLibraryId())) {
      ui.showLibrary(library.entries(), true, library.totalBytes(), library.usedBytes(),
                     library.invalidCount());
      melody.play(MelodyPlayer::Cue::TagFound);
    } else {
      ui.showDeleteResult(false);
      melody.play(MelodyPlayer::Cue::Error);
    }
  }
  if (action == UiAction::WriteSaved) beginSavedCopy(true);
  if (action == UiAction::EmulatePresent) {
    emulateTag(ui.retainedTag(), false);
    return;
  }
  if (action == UiAction::EmulateSaved) {
    emulateTag(ui.selectedSavedTag(), true);
    return;
  }
  if (action == UiAction::EmulatePreset) {
    AceTagData presetTag;
    AcePresets::buildTag(ui.selectedPreset(), presetTag);
    AceCodec::validateAndDecode(presetTag);
    emulateTag(presetTag, false, true);
    return;
  }
  if (action == UiAction::SavePreset) {
    AceTagData presetTag;
    AcePresets::buildTag(ui.selectedPreset(), presetTag);
    AceCodec::validateAndDecode(presetTag);
    assignPresetUid(presetTag);
    uint32_t savedId = 0;
    const LibrarySaveResult result = library.save(presetTag, false, savedId);
    const bool ok = result == LibrarySaveResult::Ok;
    const char *message = ok ? "Preset saved to Library" :
                          result == LibrarySaveResult::Duplicate ? "Preset already in Library" :
                          result == LibrarySaveResult::Unavailable ? "Internal storage unavailable" :
                          result == LibrarySaveResult::Full ? "Storage full - delete saved tags" :
                          result == LibrarySaveResult::InvalidSource ? "Preset data is invalid" :
                          result == LibrarySaveResult::CommitFailed ? "Could not commit saved file" :
                          "Could not write saved file";
    ui.showSaveResult(ok, savedId, message, &presetTag, true);
    melody.play(ok ? MelodyPlayer::Cue::TagFound : MelodyPlayer::Cue::Error);
  }
  if (action == UiAction::CloneStart) beginClone(true);
  if (action == UiAction::WriteArmed) beginWriteAttempt();
  if (action == UiAction::WriteRetry) {
    if (operationMode == OperationMode::Clone) beginClone(false);
    else if (operationMode == OperationMode::SavedCopy) beginSavedCopy(false);
    else beginWriteAttempt();
  }
  if (action == UiAction::WriteCancel || action == UiAction::WriteDone) {
    writeState = WriteState::Idle;
    operationMode = OperationMode::None;
    ui.setCloneMode(false);
  }
  const bool physicalOperationActive =
      writeState == WriteState::WaitingForClear ||
      writeState == WriteState::WaitingForDestination ||
      writeState == WriteState::Writing || writeState == WriteState::Verifying;
  power.update(melody.playing() || physicalOperationActive);
  if (!reader.status().found || !reader.status().samConfigured) {
    delay(20);
    return;
  }

  if (writeState == WriteState::WaitingForClear) {
    AceTagData seen;
    if (reader.detectTag(seen, 45)) clearSinceMs = 0;
    else {
      if (!clearSinceMs) clearSinceMs = millis();
      if (millis() - clearSinceMs >= 750) {
        writeState = WriteState::WaitingForDestination;
        if (isCopyMode()) ui.showCloneWaiting(cloneSource);
        else ui.showWriteWaiting(false);
        Serial.printf("[%s] Field clear; destination detection armed\n",
                      operationLogName());
      }
    }
    delay(5); return;
  }

  if (writeState == WriteState::WaitingForDestination) {
    if (!reader.detectTag(destinationTag, 60)) { delay(5); return; }
    power.wakeDisplayForRfid();
    Serial.printf("[%s] Destination UID=%s\n",
                  operationLogName(),
                  destinationTag.uidText.c_str());
    if (operationMode == OperationMode::Clone &&
        destinationTag.uidLength == cloneSource.uidLength &&
        memcmp(destinationTag.uid, cloneSource.uid, cloneSource.uidLength) == 0) {
      failWrite("SAME TAG", "Source cannot be destination"); return;
    }
    if (destinationTag.uidLength != 7) {
      failWrite("UNSUPPORTED TAG", "Expected 7-byte NTAG UID"); return;
    }
    // A complete read proves that the required user-memory range exists.
    if (!reader.readPages(destinationTag)) {
      if (reader.lastReadFailure() == ReadPagesFailure::DifferentTag) {
        failWrite("DIFFERENT TAG", "UID changed during inspection"); return;
      }
      failWrite("UNSUPPORTED TAG", "Pages 4-31 not readable"); return;
    }
    if (isCopyMode())
      melody.play(MelodyPlayer::Cue::Startup);
    writePage = 4;
    wroteAnyPage = false;
    writeStartedMs = millis();
    writeState = WriteState::Writing;
    ui.showWriteProgress(isCopyMode() ? "WRITING COPY" : "WRITING TAG", 0, 28);
    return;
  }

  if (writeState == WriteState::Writing) {
    const WritePageResult result = reader.writePageSafe(writePage, intendedTag.pages[writePage], destinationTag);
    if (result != WritePageResult::Ok) {
      if (result != WritePageResult::WriteProtected) wroteAnyPage = true;
      const char *reason = result == WritePageResult::DifferentTag ? "DIFFERENT TAG" :
                           result == WritePageResult::Removed ? "TAG REMOVED" :
                           result == WritePageResult::WriteProtected ?
                             (isCopyMode() ? "PROTECTED TAG" : "WRITE PROTECTED") :
                           result == WritePageResult::VerifyMismatch ? "VERIFY MISMATCH" : "WRITE FAILED";
      const String detail = result == WritePageResult::WriteProtected &&
                            isCopyMode()
                                ? "Factory tag cannot be overwritten"
                                : "Page " + String(writePage);
      failWrite(reason, detail); return;
    }
    wroteAnyPage = true;
    Serial.printf("[%s] P%02u: OK\n",
                  operationLogName(), writePage);
    ui.showWriteProgress(isCopyMode() ? "WRITING COPY" : "WRITING TAG",
                         writePage - 3, 28);
    if (++writePage > 31) {
      Serial.printf("[%s] All pages written in %lu ms; starting full verification\n",
                    operationLogName(),
                    millis() - writeStartedMs);
      writeState = WriteState::Verifying;
      verificationReadAttempt = 0;
      ui.showWriteProgress("VERIFYING", 0, 28);
    }
    return;
  }

  if (writeState == WriteState::Verifying) {
    ++verificationReadAttempt;
    AceTagData actual;
    if (!reader.detectTag(actual, 120)) {
      if (verificationReadAttempt < 3) {
        Serial.printf("[verify] Tag reselect failed; full-read retry %u of 3\n",
                      verificationReadAttempt + 1);
        return;
      }
      failWrite("TAG REMOVED", "Destination unavailable for verify"); return;
    }
    if (actual.uidLength != destinationTag.uidLength ||
        memcmp(actual.uid, destinationTag.uid, actual.uidLength) != 0) {
      failWrite("DIFFERENT TAG", "UID changed before verification"); return;
    }
    if (!reader.readPages(actual)) {
      if (reader.lastReadFailure() == ReadPagesFailure::DifferentTag) {
        failWrite("DIFFERENT TAG", "UID changed during verification"); return;
      }
      if (verificationReadAttempt < 3) {
        Serial.printf("[verify] Full read failed; retry %u of 3 with same UID required\n",
                      verificationReadAttempt + 1);
        return;
      }
      failWrite("VERIFY READ FAILED", "Could not read tag after 3 attempts"); return;
    }
    int8_t mismatchPage = -1;
    int8_t mismatchByte = -1;
    bool changedFromOriginal = false;
    for (uint8_t page = 4; page <= 31; ++page) {
      for (uint8_t byte = 0; byte < 4; ++byte) {
        if (actual.pages[page][byte] != destinationTag.pages[page][byte])
          changedFromOriginal = true;
        if (mismatchPage < 0 &&
            actual.pages[page][byte] != intendedTag.pages[page][byte]) {
          mismatchPage = page;
          mismatchByte = byte;
        }
      }
      if (mismatchPage < 0) Serial.printf("[verify] P%02u PASS\n", page);
      ui.showWriteProgress("VERIFYING", page - 3, 28);
    }
    if (mismatchPage >= 0) {
      Serial.printf("[%s] VERIFY FAIL page=%d byte=%d expected=0x%02X actual=0x%02X changed=%s\n",
                    isCopyMode() ? operationLogName() : "verify",
                    mismatchPage, mismatchByte,
                    intendedTag.pages[mismatchPage][mismatchByte],
                    actual.pages[mismatchPage][mismatchByte],
                    changedFromOriginal ? "YES" : "NO");
      if (!changedFromOriginal) {
        wroteAnyPage = false;
        if (isCopyMode())
          failWrite("PROTECTED TAG", "Factory tag cannot be overwritten");
        else failWrite("WRITE PROTECTED", "Factory/locked tag unchanged");
      } else {
        failWrite("VERIFY FAILED", "Mismatch page " + String(mismatchPage));
      }
      return;
    }
    Serial.printf("[%s] All cloned/written bytes PASS\n",
                  isCopyMode() ? operationLogName() : "verify");
    Serial.printf("[verify] Write plus verification completed in %lu ms\n",
                  millis() - writeStartedMs);
    if (isCopyMode())
      ui.showCloneSuccess(cloneSource, destinationTag.uidText);
    else ui.showWriteSuccess(destinationTag.uidText);
    melody.play(MelodyPlayer::Cue::TagFound);
    writeState = WriteState::Success;
    clearSinceMs = 0;
    return;
  }
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

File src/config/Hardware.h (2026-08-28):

#pragma once

#include <Arduino.h>

namespace Hardware {
constexpr uint8_t SCREEN_ROTATION = 0;
constexpr int16_t SCREEN_WIDTH = 320;
constexpr int16_t SCREEN_HEIGHT = 480;

constexpr uint8_t TFT_BACKLIGHT = 27;
constexpr uint8_t TOUCH_CS_PIN = 33;
constexpr uint8_t TOUCH_IRQ_PIN = 36;

// Confirmed by the vendor E32R35T Audio_WAV demo. GPIO26 feeds the
// onboard analog amplifier; GPIO4 enables it when driven LOW.
constexpr uint8_t AUDIO_DAC = 26;
constexpr uint8_t AUDIO_ENABLE = 4;
constexpr uint8_t BATTERY_ADC = 34;

// PN532 uses the exposed VSPI signals. The onboard SD socket shares this bus,
// but has a separate chip select (SD=GPIO5, PN532=GPIO21).
constexpr uint8_t PN532_SCK = 18;
constexpr uint8_t PN532_MISO = 19;
constexpr uint8_t PN532_MOSI = 23;
constexpr uint8_t PN532_SS = 21;
// The E32R35T exposes GPIO25 as SCL. I2C is unused in this project, so the
// pin controls the PN532 RSTPD_N input and is held LOW during deep sleep.
constexpr uint8_t PN532_RSTPD_N = 25;
}  // namespace Hardware

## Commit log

2026-08-27 Fix empty library message layout
    [Ui.cpp]
2026-08-28 Improve UI readability and PN532 sleep power
2026-08-28 Add enclosure models and project photos
    [ACE RFID Pro - Battery hold down.stl, ACE RFID Pro - Case back.stl, ACE RFID Pro - Case front.stl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]
2026-09-01 Align preset action button colors
2026-09-01 Reset PN532 before tag emulation
    [Pn532TargetEmulator.cpp, main.cpp]
2026-09-01 Revert "Restore PN532 SAM setup before emulation"
    This reverts commit 7c1143b6377384f4854c1a25a8375ea6a6f8770c.
    [main.cpp]
2026-09-01 Revert "Protect PN532 ACK timing from touch polling"
    This reverts commit 77ea532616e97212982ead0b3335bd77961ea5b8.
    [Pn532TargetEmulator.cpp]
2026-09-01 Revert "Reset PN532 before tag emulation"
    This reverts commit 4afbfbaa92d2fce77501a39f119c2c536f13db9b.
    [Pn532TargetEmulator.cpp, main.cpp]
2026-09-01 Isolate PN532 ACK from touch SPI
2026-09-01 Revert "Guard PN532 target-mode recovery"
    This reverts commit 87c46f10a420d2ee4eb9d455bc71b04a1d451077.
    [main.cpp]
2026-09-02 docs: add hardware bill of materials
2026-09-02 docs: add PN532 and battery BOM links
2026-09-02 docs: add NTAG213 tags to BOM
2026-09-02 docs: identify tactile switch as power switch
